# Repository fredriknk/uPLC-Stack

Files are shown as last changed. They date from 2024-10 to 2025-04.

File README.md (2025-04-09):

# uPLC - Miniaturized Distributed Monitoring and Control

Quick note, this is then panelization repo, head for the individual repos to get design files.

### PcbWay Sponsorship

Thanks so much to [PCBWay](https://www.pcbway.com/) for sponsoring my first assembly run for this project, they deliver awesome quality assembly service as always with 6 perfectly soldered dual sided prototypes delivered at my door in less than 2 weeks from ordering. All components perfectly placed and good quality 4 layer pcb's. I love the look and legebility of the 0.9mm inverted silkscreen texts. They even pointed out some reccomended component replacements due to NRND bom items. So Look at this beautiful trio of boards ready for automating every dumb device in my house. 

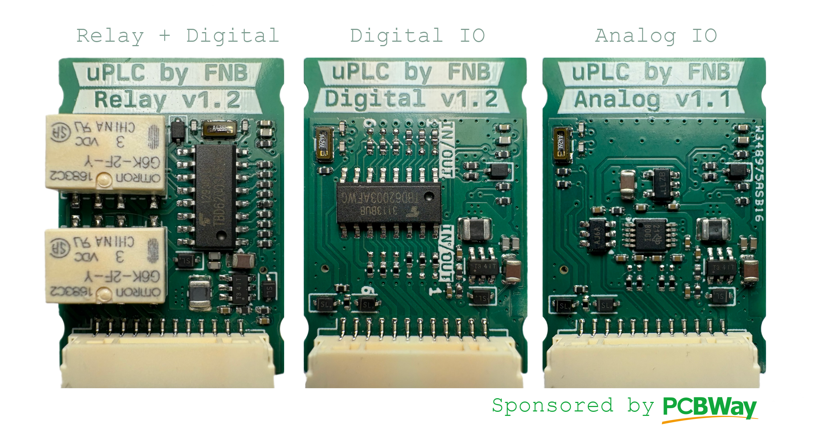
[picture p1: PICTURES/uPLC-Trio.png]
uPLC-Trio

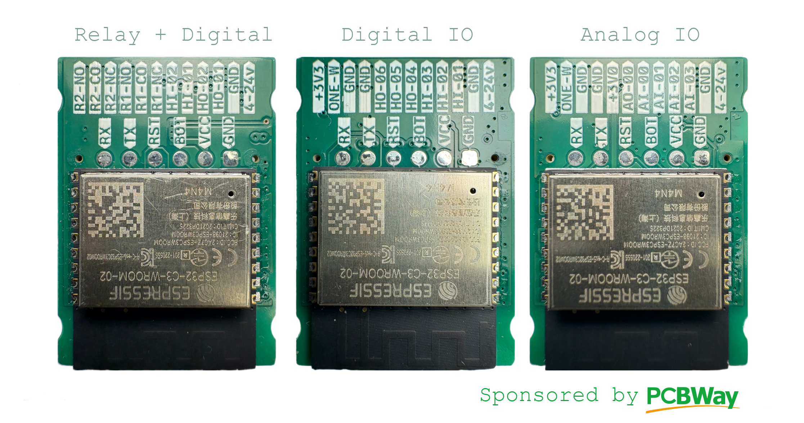
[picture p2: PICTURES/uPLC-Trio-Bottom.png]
uPLC-Trio-Bottom


ESP-Home code examples are comming soon.

The uPLC (micro Programmable Logic Controller) is a compact (22x32mm) I/O controller powered by the ESP32, designed to automate various tasks around you. So far, three versions have been developed. All versions are generally 24V-tolerant for digital I/O, except for the analog inputs, and feature a wide-range 3.8-24V buck regulator for power input.

The primary purpose of the uPLC is to "smartify" devices by integrating them with [ESPHome](https://esphome.io/). But it can also function as a direct, point-to-point PLC, using **ESP-NOW** for wireless communication, replacing traditional wired connections at a cost of latency. 

## Available Versions:
- **[uPLC-Digital](https://github.com/fredriknk/uPLC-digital):** High-speed digital I/O
- **[uPLC-Relay](https://github.com/fredriknk/uPLC-relay):** Relays and digital I/O
- **[uPLC-Analog](https://github.com/fredriknk/uPLC-Analog):** ADC and DAC

### Coming Soon:
- **uPLC-COMM:** For sensor connections- SPI, I2C, SDI12 support
- **uPLC-4_20:** Current loop for industrial sensors
- **uPLC-TBD:** If you have a good idea give me a message or issue 

## Specifications

| **Parameter** | **Description** |
|---|---|
| **Input Voltage** | 3.8-24V |
| **Current Consumption**  | TBD: WiFi Active: ##mA, Radio Off: ##mA, Deep Sleep: ##uA  |  
| **Communication** | 2.4GHz Wi-Fi, UART (TTL level) |
| **Baud Rate** | 115200 |
| **PCB Size** | 22 x 31.1 mm |
| **PCB Material** | 1.6mm FR4, HASL lead-free, 4-layer |
| **Case Size** | X x X x X mm (TBD) |

## uPLC-Stack:
To facilitate manufacturing and development, I've created a panelized version using **KiKit** scripting. The uPLC-Stack includes two units of each version, making it easier to assemble and test multiple variants in one go. Im planning on

### Running the Panelization Script:
To use the panelization script, clone all the uPLC repositories and organize them in a directory one level back from the uPLC-Stack folder. This allows the KiKit script to automatically pull in all required files for panelizing.

### Stack Images

- **Perspective View**  
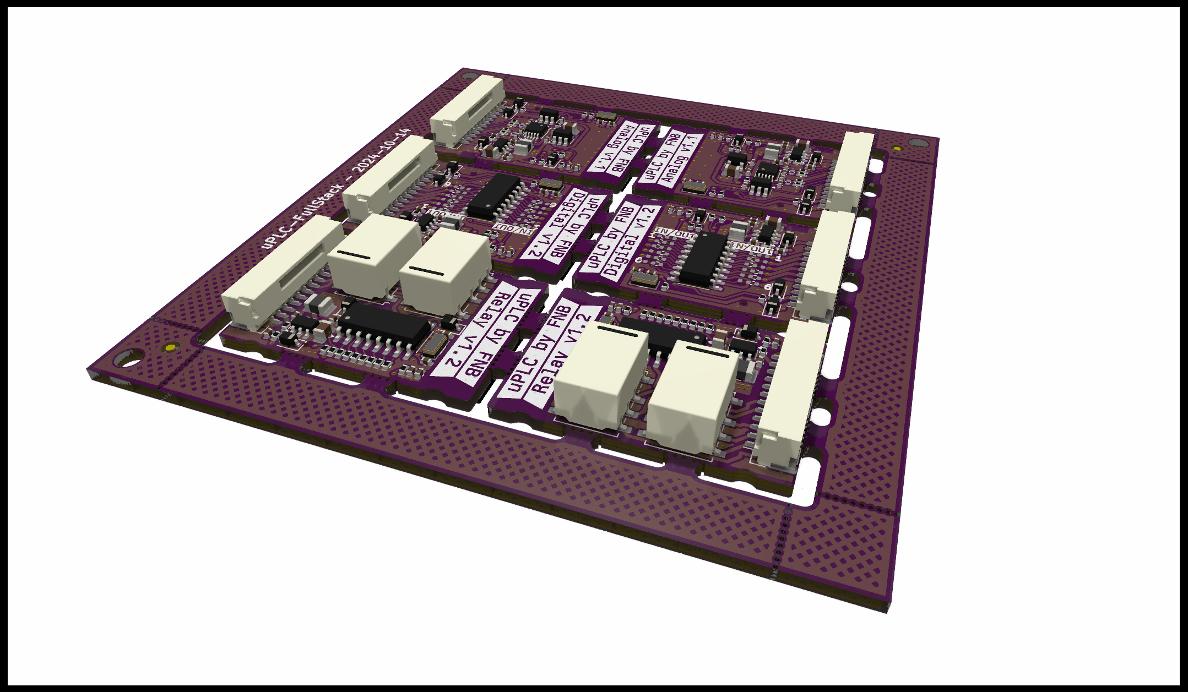
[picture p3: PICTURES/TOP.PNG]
  
  
- **Top View**  
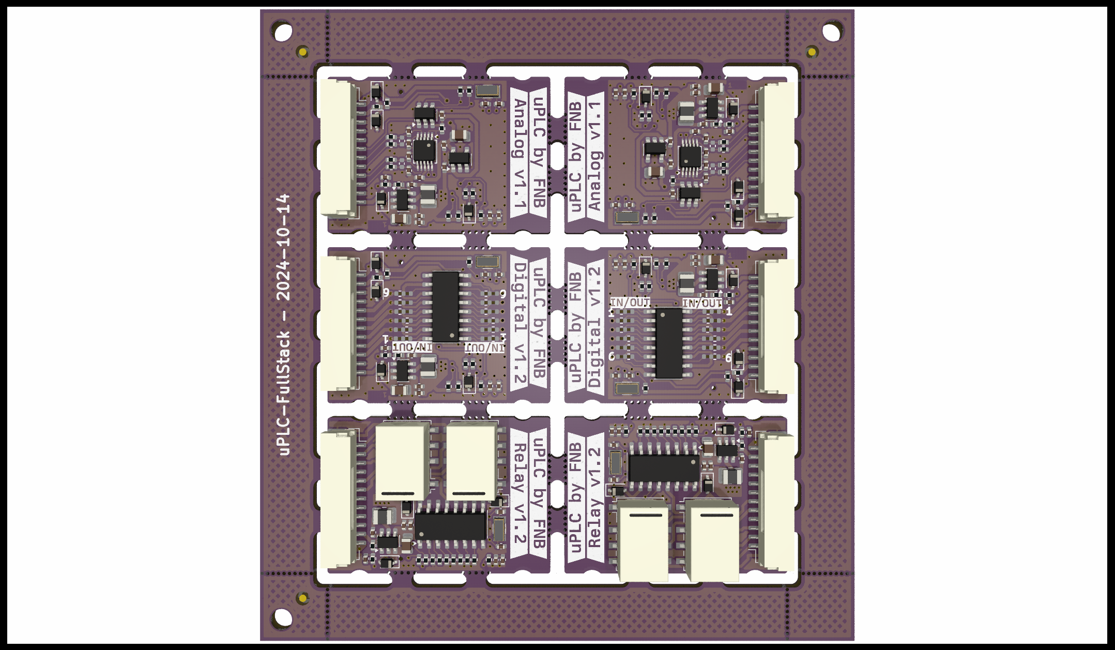
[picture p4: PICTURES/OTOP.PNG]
  

- **Side View**  
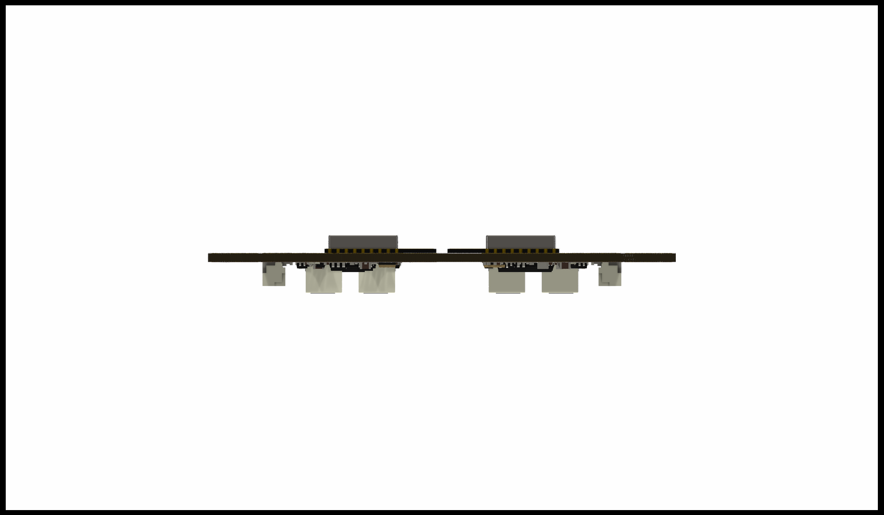
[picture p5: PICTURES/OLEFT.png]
Side
  

- **Bottom View**  
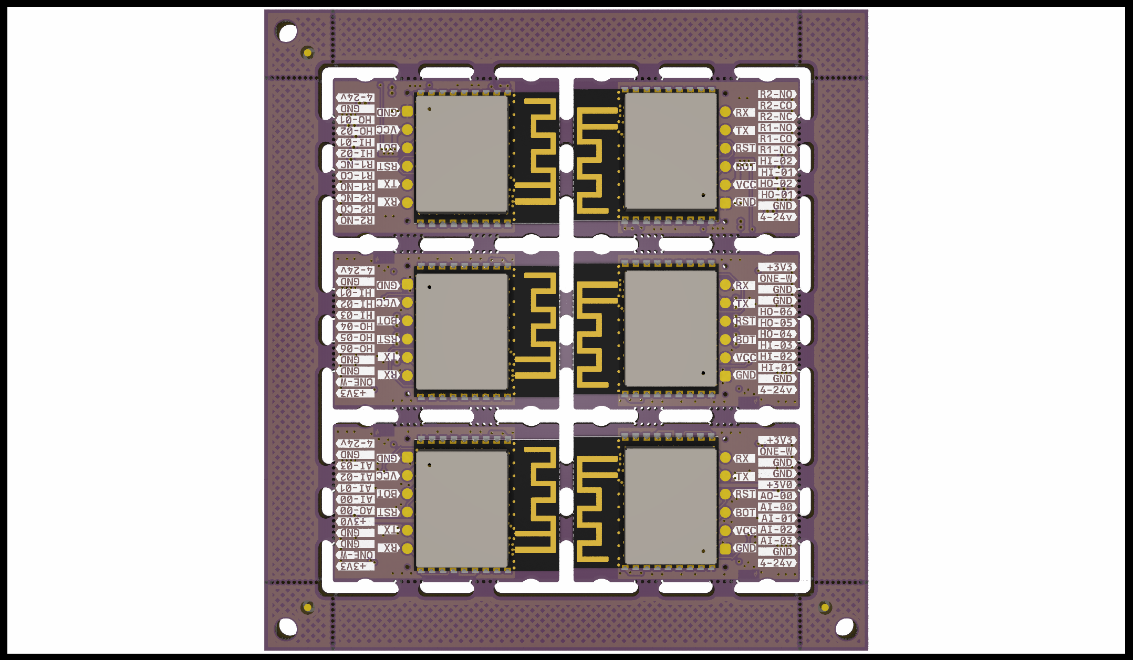
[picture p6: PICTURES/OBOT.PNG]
Back


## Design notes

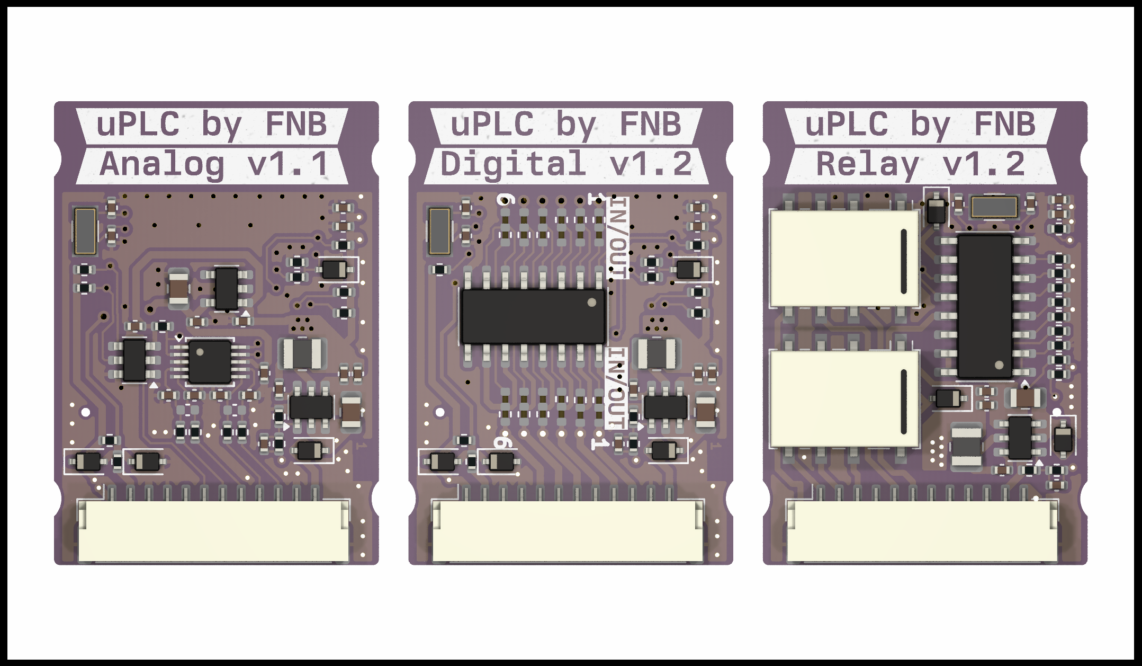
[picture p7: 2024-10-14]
PICTURES/uPLC-Trio_render.png

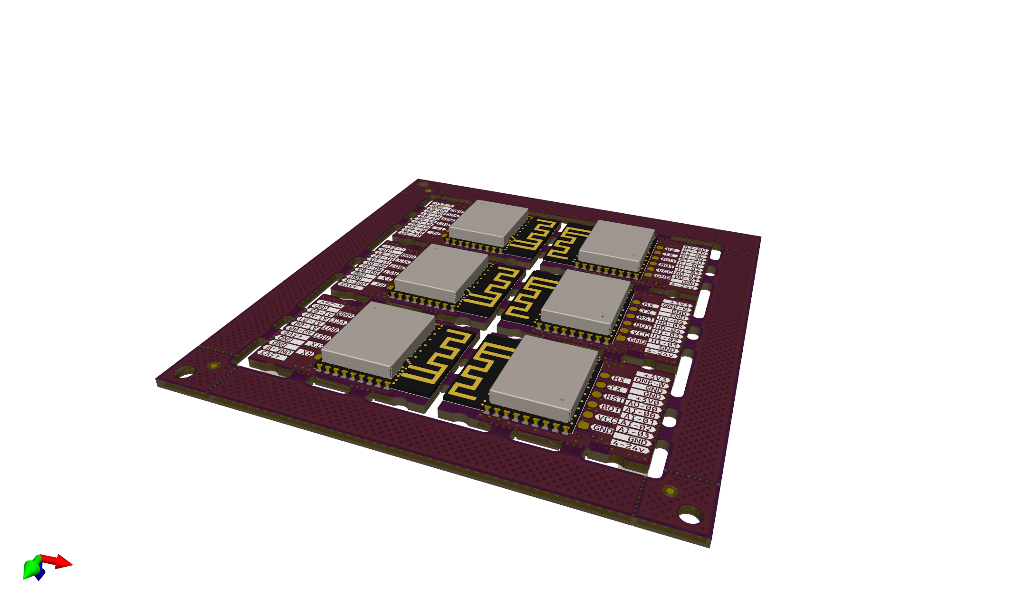
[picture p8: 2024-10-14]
PICTURES/BOTTOM.PNG

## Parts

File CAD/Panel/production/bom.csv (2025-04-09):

Designator | Footprint | Quantity | Value | LCSC Part #
C1.0, C1.1, C1.2, C4.0, C4.1, C4.2 | 0402 | 6 | 20pf | C1554
C10.0, C13.0, C14.0, C15.0, C16.0, C17.0, C18.0, C19.0, C2.0, C2.1, C2.2, C20.0, C3.0, C3.1, C3.2, C6.0, C9.0, C9.1, C9.2 | 0402 | 19 | 0.1uF | C77020
C11.0, C11.1, C11.2, C12.0, C12.1, C12.2, C8.0, C8.1, C8.2 | 0402 | 9 | 22uf | C415703
C5.0, C5.1, C5.2, C7.0 | 0805 | 4 | 10uF | C162422
D1.0, D1.1, D1.2, D2.0, D2.1, D2.2, D3.0, D3.1, D4.0, D4.1, D4.2 | D_SOD-323 | 11 | 1N5819WS | C191023
J1.0, J1.1, J1.2 | TestPoint_Pad_1.0x1.0mm_6pad | 3 | Conn_01x06_Pin | DNP
J2.0, J2.1, J2.2 | JST_GH_SM12B-GHS-TB_1x12-1MP_P1.25mm_Horizontal | 3 | SM12B-GHS-TB(LF)(SN) | C265421
JP1.1, JP10.1, JP11.1, JP12.1, JP2.1, JP3.1, JP4.1, JP5.1, JP6.1, JP7.1, JP8.1, JP9.1 | SolderJumper-3_P1.3mm_BridgedSMD12_0402 | 12 | 0R | C102746
K1.2, K2.2 | Relay_DPDT_Omron_G6K-2F-Y | 2 | G6K-2F-Y | C93168
KiKit_MB_1_1, KiKit_MB_1_2, KiKit_MB_1_3, KiKit_MB_1_4, KiKit_MB_1_5, KiKit_MB_2_1, KiKit_MB_2_2, KiKit_MB_2_3, KiKit_MB_2_4, KiKit_MB_2_5, KiKit_MB_3_1, KiKit_MB_3_2, KiKit_MB_3_3, KiKit_MB_3_4, KiKit_MB_3_5, KiKit_MB_4_1, KiKit_MB_4_2, KiKit_MB_4_3, KiKit_MB_4_4, KiKit_MB_4_5, KiKit_MB_5_1, KiKit_MB_5_2, KiKit_MB_5_3, KiKit_MB_5_4, KiKit_MB_5_5, KiKit_MB_6_1, KiKit_MB_6_2, KiKit_MB_6_3, KiKit_MB_6_4, KiKit_MB_6_5, KiKit_MB_7_1, KiKit_MB_7_2, KiKit_MB_7_3, KiKit_MB_7_4, KiKit_MB_7_5, KiKit_MB_8_1, KiKit_MB_8_2, KiKit_MB_8_3, KiKit_MB_8_4, KiKit_MB_8_5 | NPTH | 40 | NPTH
L1.0, L1.1, L1.2 | 1008 | 3 | 4.7uH | C82314
R1.0, R1.1, R1.2, R10.2, R11.2, R12.0, R12.2, R16.0, R2.0, R2.1, R2.2, R3.0, R3.1, R4.0, R4.1, R4.2, R5.0, R5.1, R5.2, R6.0, R6.1, R7.2, R8.2, R9.2 | 0402 | 24 | 10K | C25744
R10.0, R11.0, R8.0, R9.0 | 0402 | 4 | 499R | C4125
R13.0, R13.1 | 0402 | 2 | 100R | C25076
R14.0, R14.1, R14.2 | 0402 | 3 | 182k | C11481
R15.0, R15.1, R15.2 | 0402 | 3 | 62k | C137950
R7.0, R7.1 | 0402 | 2 | 309k | C159040
U1.0, U1.1, U1.2 | TSOT-23-6 | 3 | AP63201WU | C2071044
U2.0 | TSSOP-10_3x3mm_P0.5mm | 1 | ADS1115IDGS | C37593
U2.1, U2.2 | SOIC-16_3.9x9.9mm_P1.27mm | 2 | TBD62003AFWG | C114084
U3.0, U3.1, U3.2 | ESP32-C3-WROOM-02 | 3 | ESP32-C3-WROOM-02 | C2934560
U4.0 | SOT-23-5 | 1 | LP5907MFX-3.0 | C475492
U5.0 | SOT-23-6 | 1 | MCP4725xxx-xCH | C144198
Y1.0, Y1.1, Y1.2 | Crystal_SMD_3215-2Pin_3.2x1.5mm | 3 | 32.768khz 3215 12.5pf | C32346

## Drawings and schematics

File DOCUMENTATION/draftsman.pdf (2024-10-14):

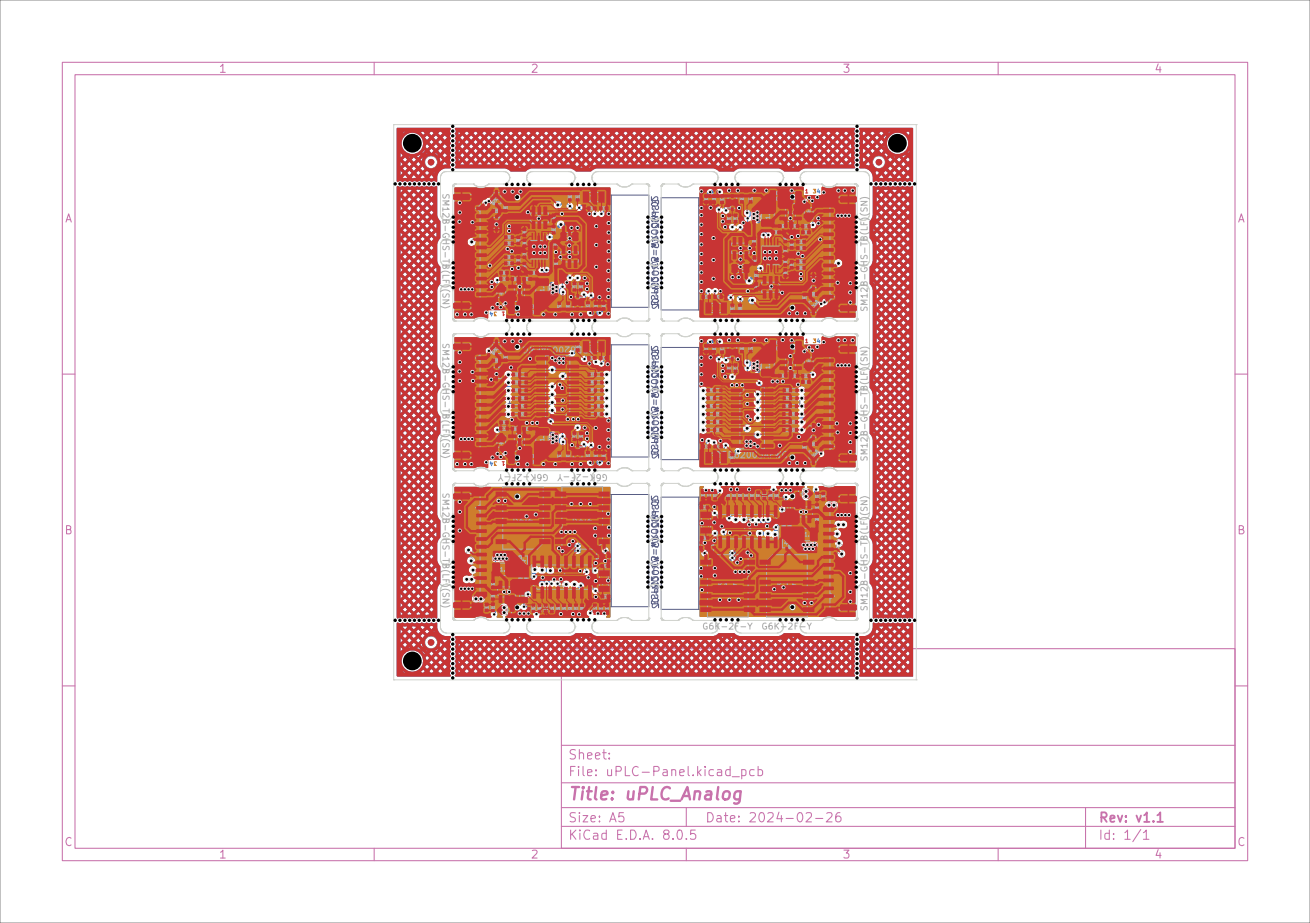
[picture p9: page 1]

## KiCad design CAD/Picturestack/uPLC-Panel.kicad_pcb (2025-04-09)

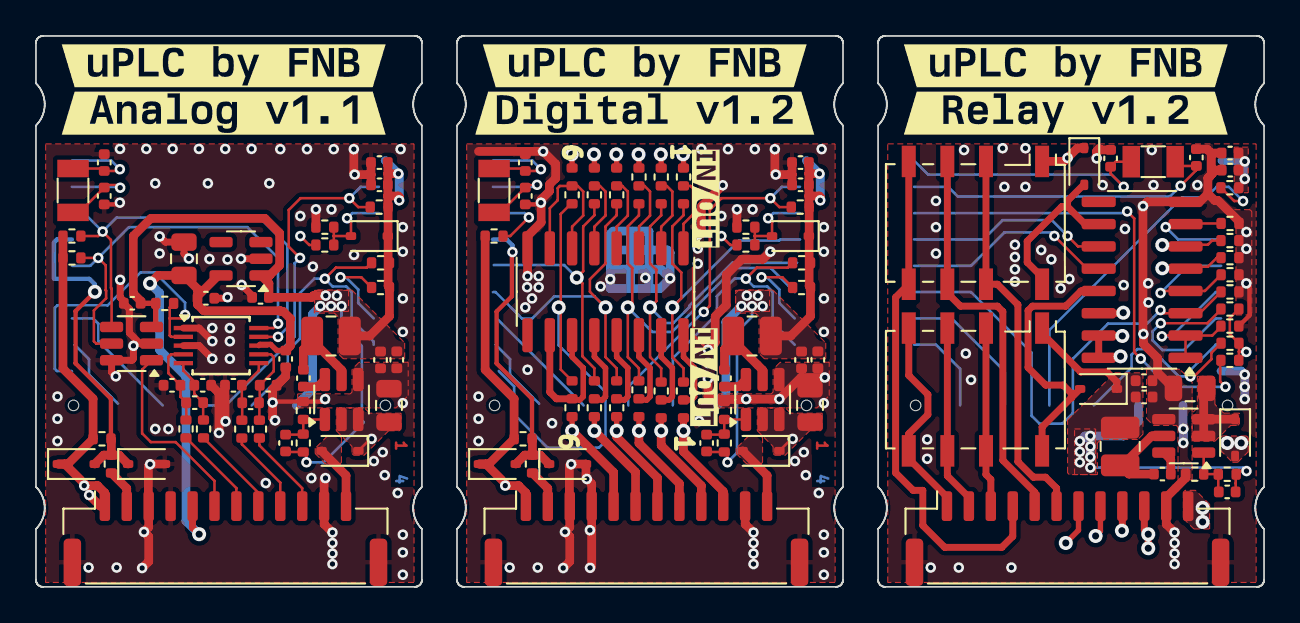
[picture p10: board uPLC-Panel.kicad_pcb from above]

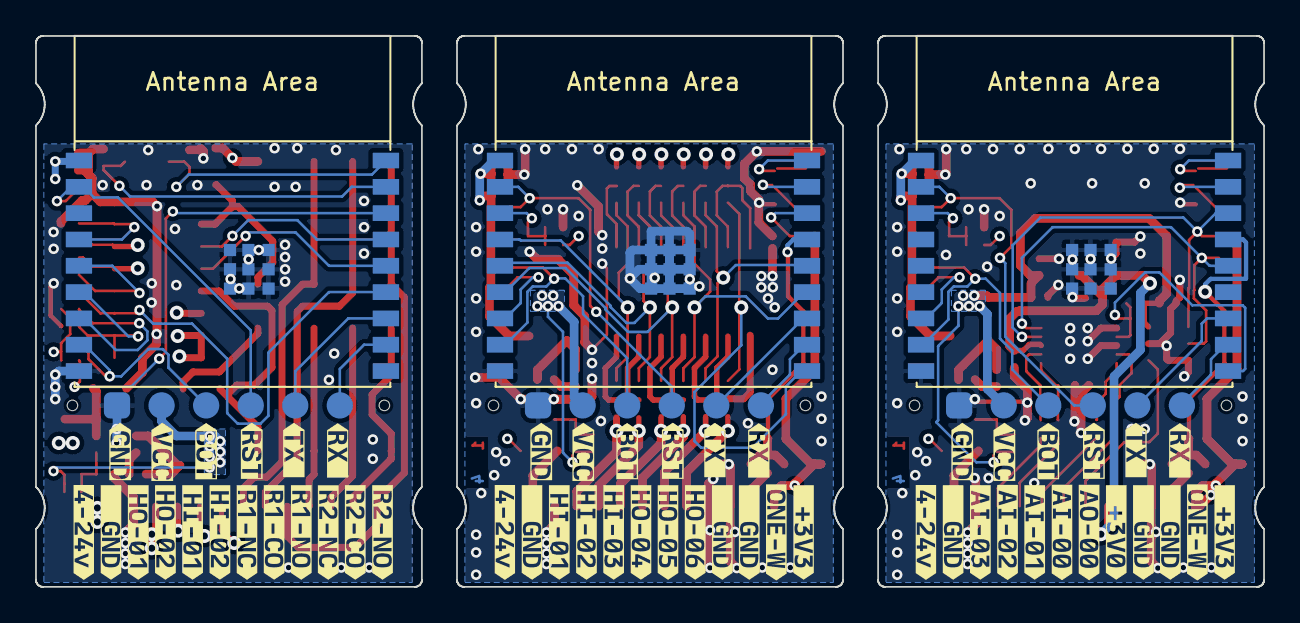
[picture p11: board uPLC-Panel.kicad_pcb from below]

Board: 4 copper layers, 70.0 x 31.4 mm, 186 parts (60 on the bottom side), 105 nets.

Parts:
C1.0, C1.1, C1.2, C4.0, C4.1, C4.2: 20pf; C_0402_1005Metric
C2.0, C2.1, C2.2, C3.0, C3.1, C3.2, C6.0, C9.0, C9.1, C9.2, C10.0, C13.0, C14.0, C15.0, C16.0, C17.0, C18.0, C19.0, C20.0: 0.1uF; C_0402_1005Metric
C5.0, C5.1, C5.2, C7.0: 10uF; C_0805_2012Metric
C8.0, C8.1, C8.2, C11.0, C11.1, C11.2, C12.0, C12.1, C12.2: 22uf; C_0402_1005Metric
D1.0, D1.1, D1.2, D2.0, D2.1, D2.2, D3.0, D3.1, D4.0, D4.1, D4.2: 1N5819WS; D_SOD-323
J1.0, J1.1, J1.2: Conn_01x06_Pin; TestPoint_Pad_1.0x1.0mm_6pad
J2.0, J2.1, J2.2: SM12B-GHS-TB(LF)(SN); JST_GH_SM12B-GHS-TB_1x12-1MP_P1.25mm_Horizontal
JP1.1, JP2.1, JP3.1, JP4.1, JP5.1, JP6.1, JP7.1, JP8.1, JP9.1, JP10.1, JP11.1, JP12.1: 0R; SolderJumper-3_P1.3mm_BridgedSMD12_0402
K1.2, K2.2: G6K-2F-Y; Relay_DPDT_Omron_G6K-2F-Y
L1.0, L1.1, L1.2: 4.7uH; L_1008_2520Metric
R1.0, R1.1, R1.2, R2.0, R2.1, R2.2, R3.0, R3.1, R4.0, R4.1, R4.2, R5.0, R5.1, R5.2, R6.0, R6.1, R7.2, R8.2, R9.2, R10.2, R11.2, R12.0, R12.2, R16.0: 10K; R_0402_1005Metric
R7.0, R7.1: 309k; R_0402_1005Metric
R8.0, R9.0, R10.0, R11.0: 499R; R_0402_1005Metric
R13.0, R13.1: 100R; R_0402_1005Metric
R14.0, R14.1, R14.2: 182k; R_0402_1005Metric
R15.0, R15.1, R15.2: 62k; R_0402_1005Metric
U1.0, U1.1, U1.2: AP63201WU; TSOT-23-6
U2.0: ADS1115IDGS; TSSOP-10_3x3mm_P0.5mm
U2.1, U2.2: TBD62003AFWG; SOIC-16_3.9x9.9mm_P1.27mm
U3.0, U3.1, U3.2: ESP32-C3-WROOM-02
U4.0: LP5907MFX-3.0; SOT-23-5
U5.0: MCP4725xxx-xCH; SOT-23-6
Y1.0, Y1.1, Y1.2: 32.768khz 3215 12.5pf; Crystal_SMD_3215-2Pin_3.2x1.5mm
kibuzzard-65D6FF37.2: G***; kibuzzard-65D6FF37
kibuzzard-65D8B0E2.1: G***; kibuzzard-65D8B0E2
kibuzzard-65D8B0ED.1: G***; kibuzzard-65D8B0ED
kibuzzard-65D8B0F8.1: G***; kibuzzard-65D8B0F8
kibuzzard-65D8B10C.1: G***; kibuzzard-65D8B10C
kibuzzard-65D8B28C.1: G***; kibuzzard-65D8B28C
kibuzzard-65D8B104.1: G***; kibuzzard-65D8B104
kibuzzard-65D8B121.1: G***; kibuzzard-65D8B121
kibuzzard-65D8B297.1: G***; kibuzzard-65D8B297
kibuzzard-65D8B343.1: G***; kibuzzard-65D8B343
kibuzzard-65D74DE1.0, kibuzzard-65D74DE1.0#2, kibuzzard-65D74DE1.1: G***; kibuzzard-65D74DE1
kibuzzard-65D74DEE.0, kibuzzard-65D74DEE.1: G***; kibuzzard-65D74DEE
kibuzzard-65D74DFB.0, kibuzzard-65D74DFB.1: G***; kibuzzard-65D74DFB
kibuzzard-65D361A7.2: G***; kibuzzard-65D361A7
kibuzzard-65D361B0.2: G***; kibuzzard-65D361B0
kibuzzard-65D361D3.2: G***; kibuzzard-65D361D3
kibuzzard-65D361E1.2: G***; kibuzzard-65D361E1
kibuzzard-65D361E9.2: G***; kibuzzard-65D361E9
kibuzzard-65D361F2.2: G***; kibuzzard-65D361F2
kibuzzard-65D361FD.2: G***; kibuzzard-65D361FD
kibuzzard-65D460A0.0, kibuzzard-65D460A0.1, kibuzzard-65D460A0.2: G***; kibuzzard-65D460A0
kibuzzard-65D3616E.0, kibuzzard-65D3616E.1, kibuzzard-65D3616E.2: G***; kibuzzard-65D3616E
kibuzzard-65D3619D.2: G***; kibuzzard-65D3619D
kibuzzard-65D3620E.2: G***; kibuzzard-65D3620E
kibuzzard-65D7176D.0, kibuzzard-65D7176D.1, kibuzzard-65D7176D.2: G***; kibuzzard-65D7176D
kibuzzard-65D7177B.0, kibuzzard-65D7177B.1, kibuzzard-65D7177B.2: G***; kibuzzard-65D7177B
kibuzzard-65D36177.0, kibuzzard-65D36177.1, kibuzzard-65D36177.2: G***; kibuzzard-65D36177
kibuzzard-65D36206.2: G***; kibuzzard-65D36206
kibuzzard-65D46022.0, kibuzzard-65D46022.1, kibuzzard-65D46022.2: G***; kibuzzard-65D46022
kibuzzard-65D46066.0, kibuzzard-65D46066.1, kibuzzard-65D46066.2: G***; kibuzzard-65D46066
kibuzzard-65D49092.0, kibuzzard-65D49092.1, kibuzzard-65D49092.2: G***; kibuzzard-65D49092
kibuzzard-65D71774.0, kibuzzard-65D71774.1, kibuzzard-65D71774.2: G***; kibuzzard-65D71774
kibuzzard-65DC95DA.0: G***; kibuzzard-65DC95DA
kibuzzard-65DC95E5.0: G***; kibuzzard-65DC95E5
kibuzzard-65DC95EF.0: G***; kibuzzard-65DC95EF
kibuzzard-65DC95F6.0: G***; kibuzzard-65DC95F6
kibuzzard-65DC961D.0: G***; kibuzzard-65DC961D
kibuzzard-65DC9610.0: G***; kibuzzard-65DC9610
kibuzzard-65DCA831.1: G***; kibuzzard-65DCA831
kibuzzard-65DCE4DE.0: G***; kibuzzard-65DCE4DE

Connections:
+3.3V.0: C3.0.1, C8.0.1, C9.0.1, C10.0.1, C11.0.1, C12.0.1, C14.0.1, D1.0.1 (K), D3.0.1 (K), J1.0.2, J2.0.1, L1.0.2, R1.0.1, R2.0.1, R4.0.2, R5.0.2, R6.0.1, R12.0.2, R14.0.2, R16.0.2, U3.0.1 (3V3), U4.0.1 (IN), U5.0.3 (VDD)
+3.3V.1: C3.1.1, C8.1.1, C9.1.1, C11.1.1, C12.1.1, D1.1.1 (K), D3.1.1 (K), J1.1.2, J2.1.1, L1.1.2, R1.1.1, R2.1.1, R4.1.2, R5.1.2, R6.1.1, R14.1.2, U3.1.1 (3V3)
+3.3V.2: C3.2.1, C8.2.1, C9.2.1, C11.2.1, C12.2.1, D1.2.1 (K), D2.2.1 (K), J1.2.2, K1.2.1, K2.2.1, L1.2.2, R1.2.1, R2.2.1, R4.2.2, R5.2.2, R14.2.2, U3.2.1 (3V3)
+3V0.0: C6.0.1, C7.0.1, C13.0.1, J2.0.5, U2.0.8 (VDD), U4.0.5 (OUT)
+VDC.0: D4.0.2 (A), J2.0.12
+VDC.1: D4.1.2 (A), J2.1.12
+VDC.2: D4.2.2 (A), J2.2.12
/FB.0: C9.0.2, R14.0.1, R15.0.2, U1.0.1 (FB)
/FB.1: C9.1.2, R14.1.1, R15.1.2, U1.1.1 (FB)
/FB.2: C9.2.2, R14.2.1, R15.2.2, U1.2.1 (FB)
/I1.1: JP1.1.2 (C), U2.1.1 (I1)
/I2.1: JP3.1.2 (C), U2.1.2 (I2)
/I3.1: JP5.1.2 (C), U2.1.3 (I3)
/I4.1: JP7.1.2 (C), U2.1.4 (I4)
/I5.1: JP9.1.2 (C), U2.1.5 (I5)
/I6.1: JP11.1.2 (C), U2.1.6 (I6), U2.1.7 (I7)
/O1.1: JP2.1.2 (C), U2.1.16 (O1)
/O2.1: JP4.1.2 (C), U2.1.15 (O2)
/O3.1: JP6.1.2 (C), U2.1.14 (O3)
/O4.1: JP8.1.2 (C), U2.1.13 (O4)
/O5.1: JP10.1.2 (C), U2.1.12 (O5)
/O6.1: JP12.1.2 (C), U2.1.10 (O7), U2.1.11 (O6)
/SW.0: C2.0.1, L1.0.1, U1.0.5 (SW)
/SW.1: C2.1.1, L1.1.1, U1.1.5 (SW)
/SW.2: C2.2.1, L1.2.1, U1.2.5 (SW)
/VIN_P.0: C5.0.1, D4.0.1 (K), R7.0.1, U1.0.2 (EN), U1.0.3 (IN)
/VIN_P.1: C5.1.1, D4.1.1 (K), R7.1.1, U1.1.2 (EN), U1.1.3 (IN)
/VIN_P.2: C5.2.1, D4.2.1 (K), U1.2.2 (EN), U1.2.3 (IN)
ADC.0: D3.0.2 (A), R3.0.1, R7.0.2, U3.0.3 (GPIO4/ADC1_CH4)
ADC.1: D3.1.2 (A), R3.1.1, R7.1.2, U3.1.3 (GPIO4/ADC1_CH4)
ADC_DRDY.0: R12.0.1, U2.0.2 (ALERT/RDY), U3.0.10 (GPIO10)
AIN0.0: J2.0.7, R8.0.2
AIN1.0: J2.0.8, R9.0.2
AIN2.0: J2.0.9, R10.0.2
AIN3.0: J2.0.10, R11.0.2
AOUT0.0: J2.0.6, U5.0.1 (VOUT)
BOOT.0: J1.0.3, R2.0.2, U3.0.8 (GPIO9)
BOOT.1: J1.1.3, R2.1.2, U3.1.8 (GPIO9)
BOOT.2: J1.2.3, R2.2.2, U3.2.8 (GPIO9)
GND.0: C1.0.1, C3.0.2, C4.0.2, C5.0.2, C6.0.2, C7.0.2, C8.0.2, C10.0.2, C11.0.2, C12.0.2, C13.0.2, C14.0.2, C15.0.1, C16.0.1, C17.0.1, C18.0.1, D2.0.2 (A), J1.0.1, J2.0.3, J2.0.4, J2.0.11, J2.0.MP (Pin_13), R3.0.2, R15.0.1, U1.0.4 (GND), U2.0.1 (ADDR), U2.0.3 (GND), U3.0.9 (GND), U3.0.19 (GND), U4.0.2 (GND), U5.0.2 (VSS), U5.0.6 (A0)
GND.1: C1.1.1, C3.1.2, C4.1.2, C5.1.2, C8.1.2, C11.1.2, C12.1.2, D2.1.2 (A), J1.1.1, J2.1.3, J2.1.4, J2.1.11, J2.1.MP (Pin_13), R3.1.2, R15.1.1, U1.1.4 (GND), U2.1.8 (GND), U3.1.9 (GND), U3.1.19 (GND)
GND.2: C1.2.1, C3.2.2, C4.2.2, C5.2.2, C8.2.2, C11.2.2, C12.2.2, J1.2.1, J2.2.11, J2.2.MP (Pin_13), R7.2.2, R8.2.2, R9.2.2, R10.2.2, R11.2.2, R12.2.2, R15.2.1, U1.2.4 (GND), U2.2.8 (GND), U3.2.9 (GND), U3.2.19 (GND)
H1.1: J2.1.10, JP1.1.1 (A), JP2.1.3 (B)
H2.1: J2.1.9, JP3.1.1 (A), JP4.1.3 (B)
H3.1: J2.1.8, JP5.1.1 (A), JP6.1.3 (B)
H4.1: J2.1.7, JP7.1.3 (B), JP8.1.1 (A)
H5.1: J2.1.6, JP9.1.3 (B), JP10.1.1 (A)
H6.1: J2.1.5, JP11.1.3 (B), JP12.1.1 (A)
HI1.2: J2.2.8, R12.2.1, U2.2.5 (I5)
HI2.2: J2.2.7, R11.2.1, U2.2.6 (I6)
HO1.2: J2.2.10, U2.2.15 (O2), U2.2.16 (O1)
HO2.2: J2.2.9, U2.2.14 (O3)
L1.1: JP1.1.3 (B), JP2.1.1 (A), U3.1.4 (GPIO5/ADC2_CH0)
L2.1: JP3.1.3 (B), JP4.1.1 (A), U3.1.5 (GPIO6)
L3.1: JP5.1.3 (B), JP6.1.1 (A), U3.1.6 (GPIO7)
L4.1: JP7.1.1 (A), JP8.1.3 (B), U3.1.13 (GPIO18/USB_D-)
L5.1: JP9.1.1 (A), JP10.1.3 (B), U3.1.14 (GPIO19/USB_D+)
L6.1: JP11.1.1 (A), JP12.1.3 (B), U3.1.10 (GPIO10)
LI3.2: R8.2.1, U2.2.3 (I3), U3.2.13 (GPIO18/USB_D-)
LI4.2: R9.2.1, U2.2.4 (I4), U3.2.5 (GPIO6)
LI5.2: R10.2.1, U2.2.7 (I7), U3.2.4 (GPIO5/ADC2_CH0)
LI12.2: R7.2.1, U2.2.1 (I1), U2.2.2 (I2), U3.2.6 (GPIO7)
LO6.2: U2.2.12 (O5), U3.2.14 (GPIO19/USB_D+)
LO7.2: U2.2.11 (O6), U3.2.15 (GPIO3/ADC1_CH3)
unnamed: C2.0.2, U1.0.6 (BST)
unnamed: C2.1.2, U1.1.6 (BST)
unnamed: C2.2.2, U1.2.6 (BST)
unnamed: C15.0.2, C19.0.1, R8.0.1, U2.0.4 (AIN0)
unnamed: C16.0.2, C19.0.2, R9.0.1, U2.0.5 (AIN1)
unnamed: C17.0.2, C20.0.1, R10.0.1, U2.0.6 (AIN2)
unnamed: C18.0.2, C20.0.2, R11.0.1, U2.0.7 (AIN3)
unnamed: C1.0.2, U3.0.18 (GPIO0/ADC1_CH0/XTAL_32K_P), Y1.0.2
unnamed: C1.1.2, U3.1.18 (GPIO0/ADC1_CH0/XTAL_32K_P), Y1.1.2
unnamed: C1.2.2, U3.2.18 (GPIO0/ADC1_CH0/XTAL_32K_P), Y1.2.2
unnamed: C4.0.1, U3.0.17 (GPIO1/ADC1_CH1/XTAL_32K_N), Y1.0.1
unnamed: C4.1.1, U3.1.17 (GPIO1/ADC1_CH1/XTAL_32K_N), Y1.1.1
unnamed: C4.2.1, U3.2.17 (GPIO1/ADC1_CH1/XTAL_32K_N), Y1.2.1
unnamed: R5.1.1, U3.1.16 (GPIO2/ADC1_CH2)
unnamed: R5.2.1, U3.2.16 (GPIO2/ADC1_CH2)
unnamed: R4.0.1, U3.0.7 (GPIO8)
unnamed: R4.1.1, U3.1.7 (GPIO8)
unnamed: R4.2.1, U3.2.7 (GPIO8)
ONEWIRE.0: D1.0.2 (A), D2.0.1 (K), R6.0.2, R13.0.2, U3.0.15 (GPIO3/ADC1_CH3)
ONEWIRE.1: D1.1.2 (A), D2.1.1 (K), R6.1.2, R13.1.2, U3.1.15 (GPIO3/ADC1_CH3)
ONEWIRE_OUT.0: J2.0.2, R13.0.1
ONEWIRE_OUT.1: J2.1.2, R13.1.1
R1CO.2: J2.2.5, K1.2.3, K1.2.6
R1NC.2: J2.2.6, K1.2.2, K1.2.7
R1NO.2: J2.2.4, K1.2.4, K1.2.5
R2CO.2: J2.2.2, K2.2.3, K2.2.6
R2NC.2: J2.2.3, K2.2.2, K2.2.7
R2NO.2: J2.2.1, K2.2.4, K2.2.5
RO1.2: D1.2.2 (A), K1.2.8, U2.2.10 (O7)
RO2.2: D2.2.2 (A), K2.2.8, U2.2.13 (O4)
RST.0: J1.0.4, R1.0.2, U3.0.2 (EN/CHIP_PU)
RST.1: J1.1.4, R1.1.2, U3.1.2 (EN/CHIP_PU)
RST.2: J1.2.4, R1.2.2, U3.2.2 (EN/CHIP_PU)
RX.0: J1.0.6, U3.0.11 (GPIO20/U0RXD)
RX.1: J1.1.6, U3.1.11 (GPIO20/U0RXD)
RX.2: J1.2.6, U3.2.11 (GPIO20/U0RXD)
SCL.0: R16.0.1, U2.0.10 (SCL), U3.0.14 (GPIO19/USB_D+), U5.0.5 (SCL)
SDA.0: R5.0.1, U2.0.9 (SDA), U3.0.16 (GPIO2/ADC1_CH2), U5.0.4 (SDA)
TX.0: J1.0.5, U3.0.12 (GPIO21/U0TXD)
TX.1: J1.1.5, U3.1.12 (GPIO21/U0TXD)
TX.2: J1.2.5, U3.2.12 (GPIO21/U0TXD)

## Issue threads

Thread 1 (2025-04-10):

Feature: board with industrial 0 - 10V input/output

JirikP, 2025-04-10:
Love your work, i am working on something similar, but connected via LAN and hopefully poe powered.
I would love to see a 0 - 10 V for bridging HA to devices like heat pumps or forced ventilation units. The usually come with their own expensive and ugly sensors that have 0-10V. I want to use my CO2 meter or temperature and "inject" the value to the ventilation unit.

fredriknk, 2025-04-10:
Hmmh! Yeah quite a few have requested a POE version..! It would be quite nice with a POE 0-10V adc/dac and a 4-20ma, i will start to draft up some design ideas

JirikP, 2025-04-10:
- DFRobot has some cool board with 0-10V [here](https://wiki.dfrobot.com/SKU_DFR0971_2_Channel_I2C_0_10V_DAC_Module). I planned to use that chip for my board.

- The poe is tricky. I wanted 2 pairs for data with power (ESPHome doesnt support wifi and lan together) and the other 2 pairs as output for the 0-10V or 4-20mA. But on the other side you need to custom crimp the RJ45, dont mess up and connect the signal pairs to respective machines that dont have to be close to the rack or poe switch.

- Many, for me, were complaining that LAN without POE is loosing the convenience, but were short to understand that even with poe they would have to crimp their own out of spec cables.

- For me its balance of reliability and ease of use.
    - easy: Random sensor to HA and your ESP32 with 0-10V output to the ventilation unit. But if HA goes down my house is crippled
    - LAN + custom RJ45 cable: ESP with I2C sensors and outputs 0-10V directly to HVAC. Connection to HA is just for monitoring and remote use.

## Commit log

2024-10-14 Readme update and picture stack
    [bom.csv, designators.csv, positions.csv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]
2025-04-09 Feat: Prodrun
    [bom.csv, designators.csv, positions.csv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]
